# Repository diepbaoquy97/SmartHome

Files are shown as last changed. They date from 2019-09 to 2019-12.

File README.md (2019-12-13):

# Capstone Project
# Fall 2019

##SmartHome
----------
1. [Introduction](#introduction)
2. [Budget](#budget)
3. [Time Commitment](#time-committment)
4. [Mechanical Assembly](#mechanical-assembly)
5. [PCB/ Sodering](#pcb-soldering)
6. [Unit testing](#unit-testing)
7. [Power up](#power-up)
8. [Production Testing](#production-testing)

## Introduction

This is a tutorial which help you do the measuring temperature that using temperature sensor which names MCP9808. This hardware project is used to help the software project name SmartHome. The smarthome app will have some function such as temperature reading, door status, light control. Then the app will control these hardware. This help user overview and control their house easily.

To read the temperature from MCP9808 sensor, we use Raspberry pi 4 with a SD card contain Raspian and we use Linux to write a C program to read the temperature. First, we design the PCB board and do the solder to the socket into PCB. Then we just need to plug in the Raspberry and MCP9808 sensor to the PCB board.

I use the fritzing software to design the PCB board and send it to Humber prototype lab to make the PCB board. The fritzing file could be found [here](https://github.com/diepbaoquy97/SmartHome/blob/master/BaoQuyDiep-Latest.fzz)

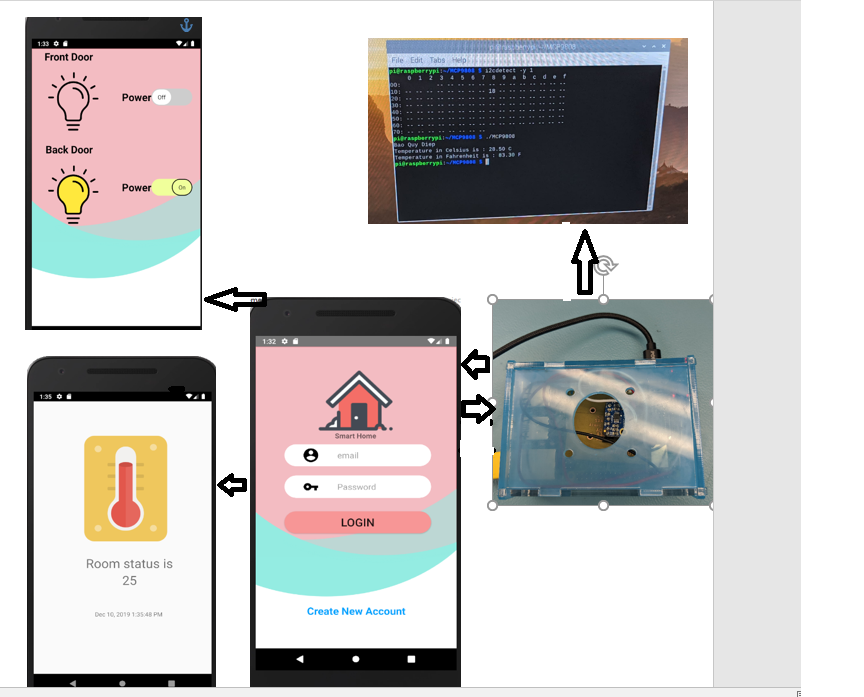
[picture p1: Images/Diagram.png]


## Budget
For me, my budget is approximate $100. The sensor was cheap. The most money I spend is Raspberry. Below is my budget
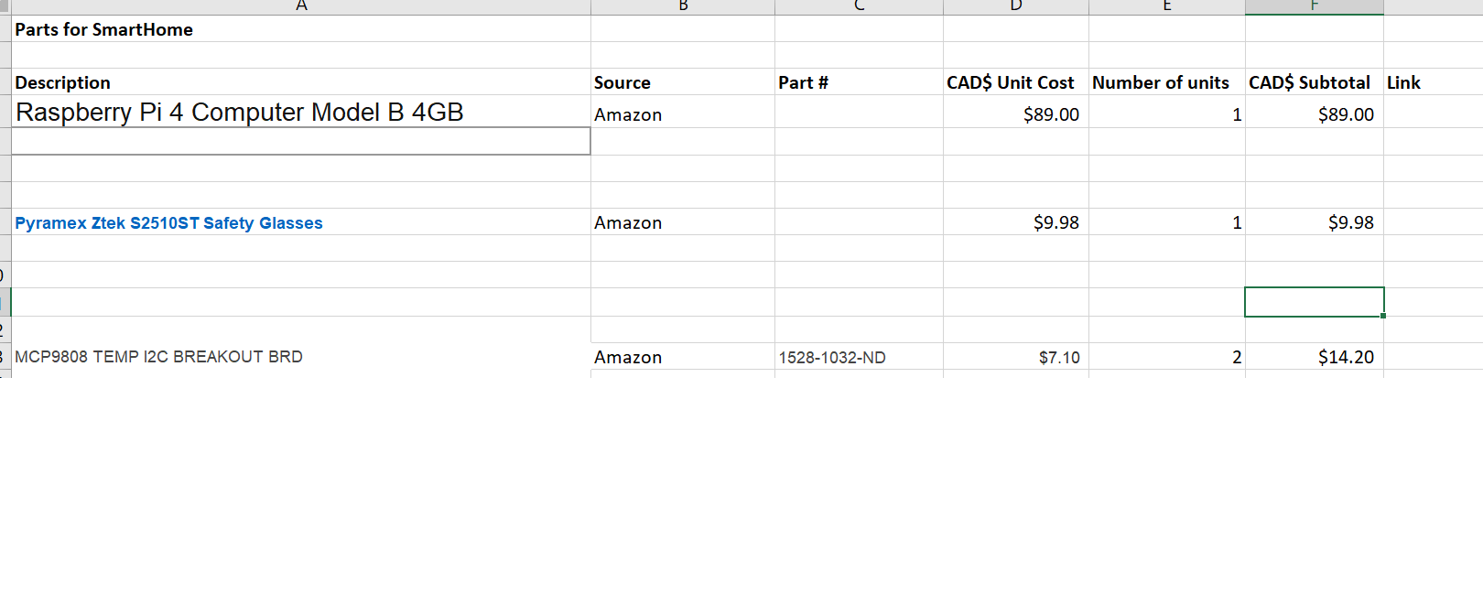
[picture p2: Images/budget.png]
budget


The parts that I got later is 

| Part | Number |
| --- | --- |
| Micro HDMI | 1 |
| USB to Ethernet cable | 1 |
| Raspberry fan | 1 |

I also got 2 x 8 pin socket from the prototype lab

## Time committment 
For this hardware project, it is easy to do and take about 9 hours to comple the project. We just need basic knowledge about circuit connection, soldering skill, Raspberry power up,etc. The longest time is that we have to wait for the parts we order and we also have to wait 2-3 business day for the prototype lab make our PCB board.

| Task | Time |
| --- | --- |
| Ordering | 90 minutes |
| PCB design | 120 minutes |
| Soldering | 60 minutes |
| PCB power up | 120 minutes |
| Enclosure disign | 90 minutes |
| Enclosure pritting | 45 minutes |

In total, It takes approximately 9 hours to complete this project

## Mechanical Assembly
First, we need to connect the circuit from Raspberry to MCP9808 in order to read the temperature. There are 4 pin connection.
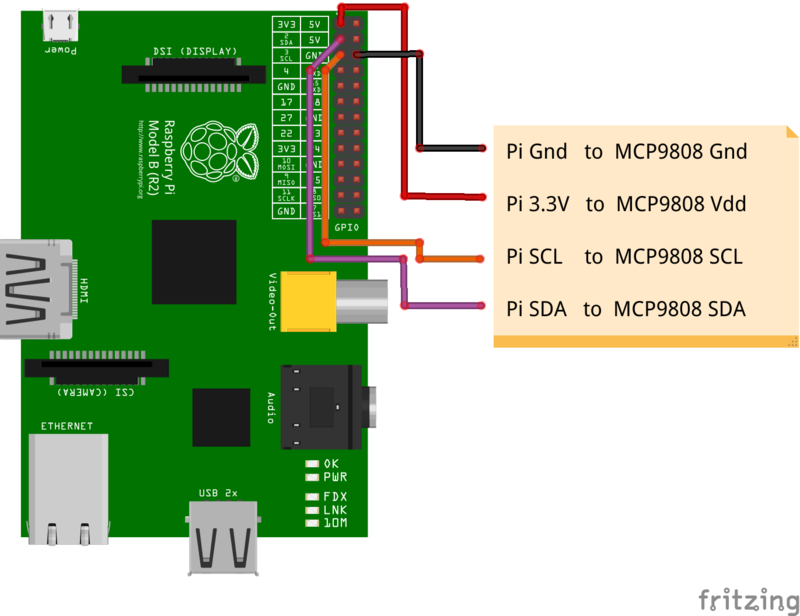
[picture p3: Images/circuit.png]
Circuit


The enclosure for raspberry is designed by the software names Coreldraw. The coreldraw design can be found 
[here](https://github.com/diepbaoquy97/SmartHome/blob/master/BaoCorel17comple.cdr)

The closure could be either printed in prototype lab or private outsite 3D printer.
The example images about enclosure could be found below:
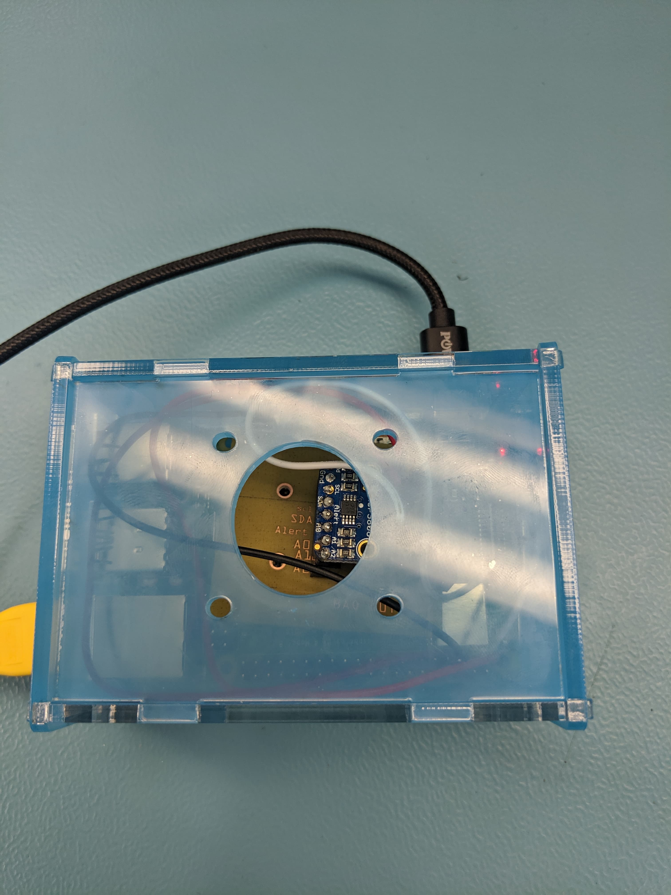
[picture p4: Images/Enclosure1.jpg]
Enclosure1

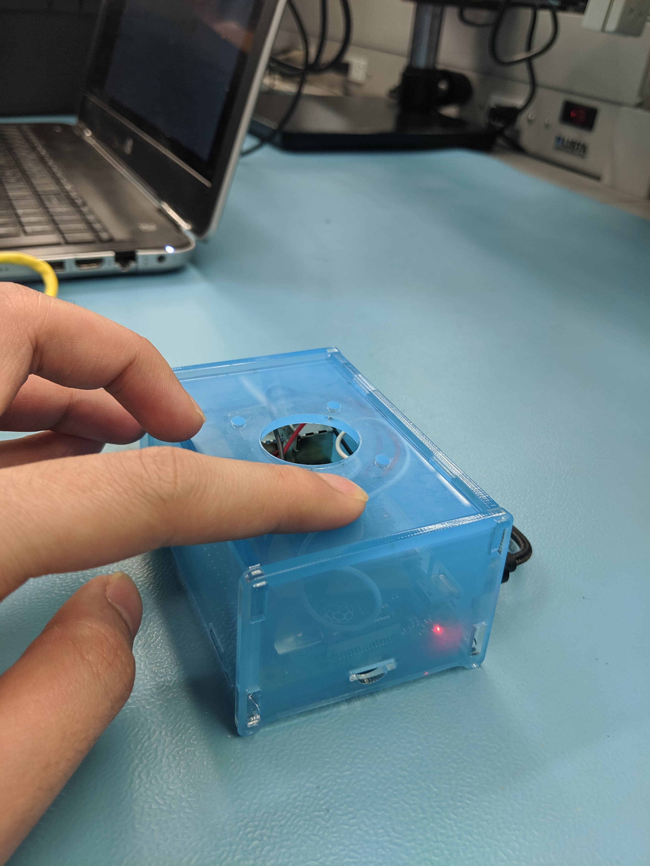
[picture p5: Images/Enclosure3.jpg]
Enclosure3

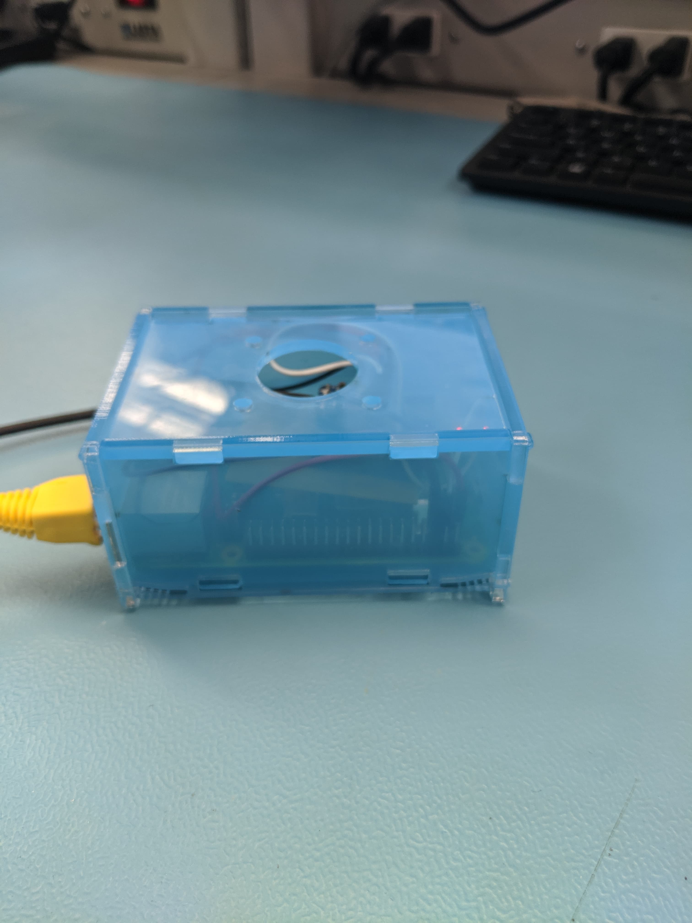
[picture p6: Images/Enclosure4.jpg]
Enclosure4

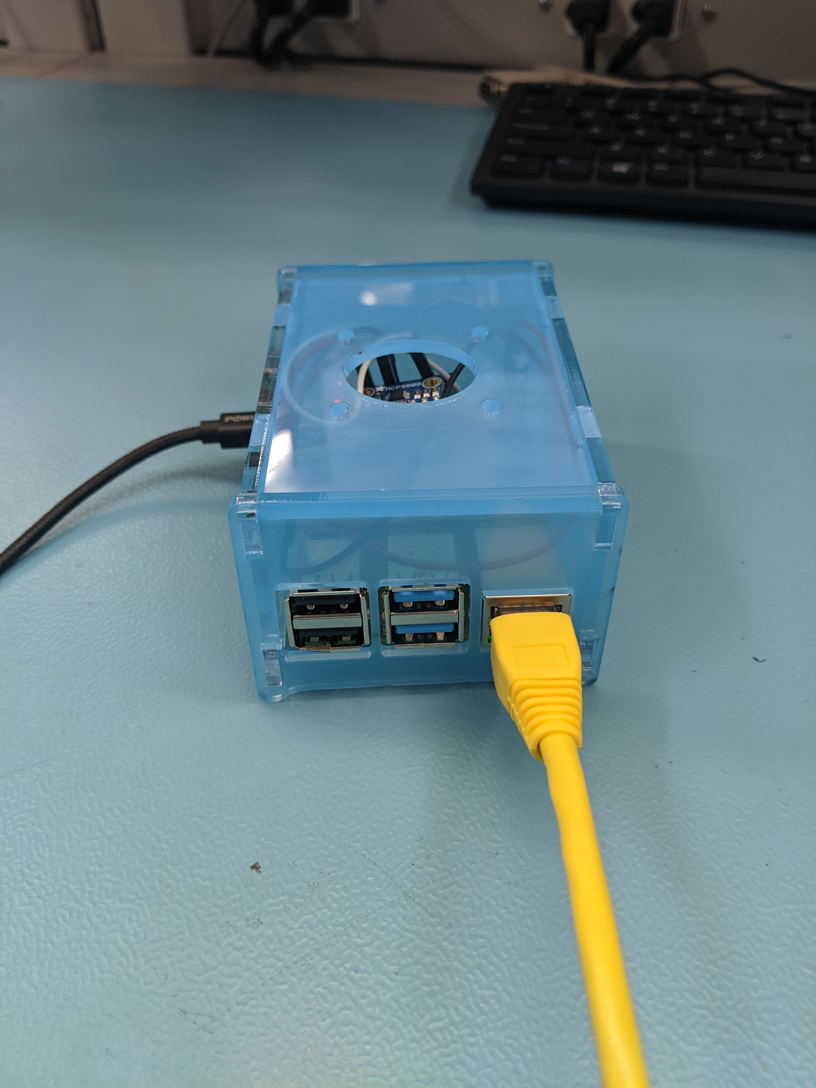
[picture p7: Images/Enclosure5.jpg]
Enclosure5

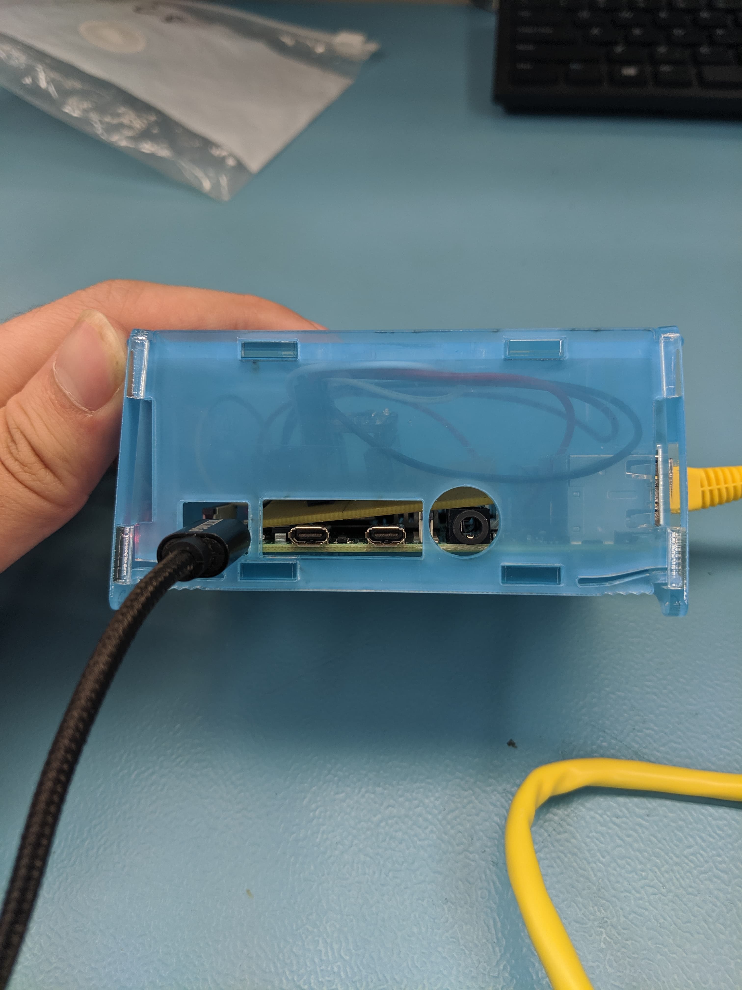
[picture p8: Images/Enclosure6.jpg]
Enclosure6

For the case, just be careful when you put it into the case because it is easy to break

## PCB Soldering
The PBC board must be soldered in order to get connection. We use the socket and put it into the holes and solder it together. Then we just need to plug in the sensor into the socket
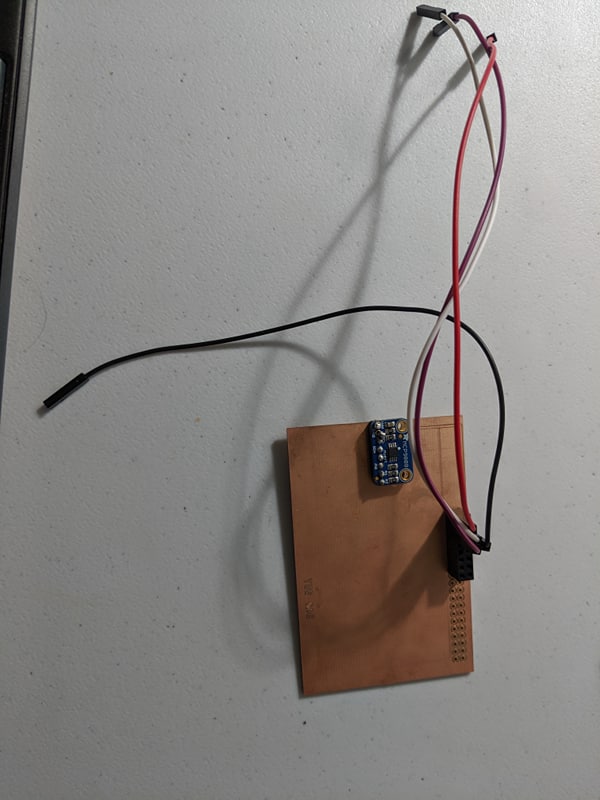
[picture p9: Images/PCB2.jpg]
PCB2


You could found a lot of tutorial about soldering online. Below is the video I found only, it is useful to help solder
[here](https://www.youtube.com/watch?v=aP_ebVWYzSk)

Below is the circuit that we need to solder

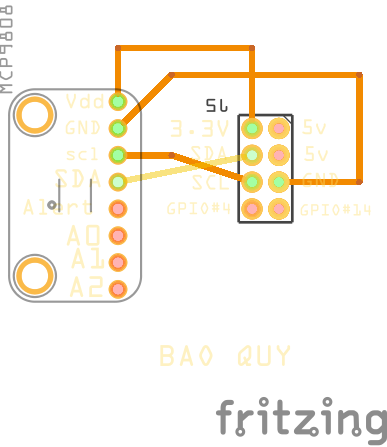
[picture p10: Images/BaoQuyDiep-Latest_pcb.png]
Solder


Warning: Do not solder the sensor directly to the board, we are suppose to solder the socket into the PCB. Be careful when you solder, do not solder too thick it will connect two holes together or too thin and that won't get the connection.

## Unit Testing

### Sensor testing
We have to test the sensor first to see if the sensor function propely. We plug the sensor into the breadboard and use the wire to get connection between Raspberry and sensor. Using the command (sudo i2cdetect -y -1) to see if the connection establish. If it doesn't show up, it means there is no any connection between Raspberry and sensor. So in this case, we should re-check the circuit.
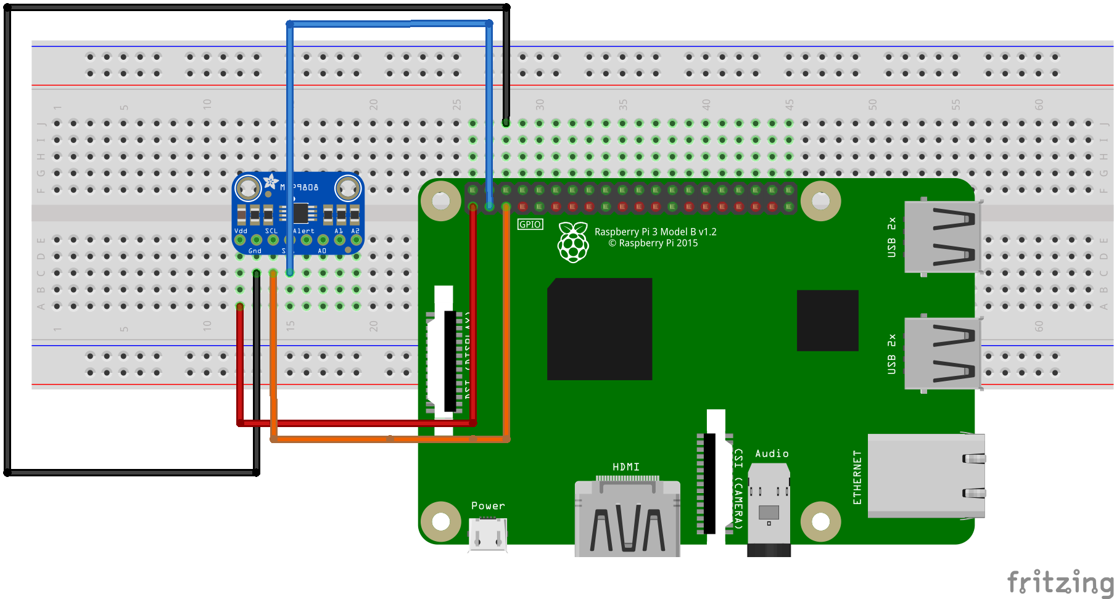
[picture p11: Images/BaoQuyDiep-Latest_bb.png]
Breadboard


If the sensor works properly, then we move on PCB testing.

### PCB testing
Once the PCB get soldered, we have to test all the connection to see if it is propely. First, we use the multimeter to test the connection between Vdd and Ground. If there is overload resistance between them, so there is no connection and this is what we expect. Then move on check the connection between other pin.
If there are incidents that two holes connect together, we could possibly to de-soldering but it will be hard

## Power up

To power up the Raspberry, we need an SD card to load the OS inside it. The link to raspbian is 
[here](https://www.raspberrypi.org/downloads/raspbian/). We recommend to load the virsion name Raspbian Buster with desktop and recommended software because it has full functionality. 

After you download the OS, leave it as zip file. Then download the software call Etcher, you can find it 
[here](https://www.balena.io/etcher/). This software is to flash the Image OS into the SD card. After you load the OS into SD card, insert it into the raspberry. Plug in the power supple

The one time set up is easy, so just follow the step on the OS.

After set everything up, the C file that use to read the temperature could be found 
[here](https://github.com/diepbaoquy97/SmartHome/blob/master/MCP9808.c)
Use the command: gcc -g -o MCP9808 MCP9808.c to complie. Then the execution file will be MCP9808.
#### Notice: If you use the Raspberry 4, it requires lot ofs voltage to power it on. So you should get power supply which support the high voltage. Or another way is to plug it in the USB 3.0 port, it also produces high voltage.

## Production Testing

This is the final testing to make sure the whole project works propely as we expect. Running the wire through the Raspberry case and connect with power supply, ethernet cable. Now running the code that read the temperature and see if it can read the temperature propely by placing your hand on the sensor and then put your hand off the sensor.

This is the concludes the end of build instruction, I hope that you successfully set up the project.

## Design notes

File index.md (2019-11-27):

  
# The CENG 317 smart home
# My Blog

The project is Smart home control. Its functionality is to overview and control the house, reading and set temperature, detect obstacle using motion sensor. It helps people manage home easily and safely.  

# Table of contents
# Week 12: Presentation
This week is presentation about what the project. Below is my powerpoint file. My progress is up to date and my budget is good, there is nothing new to buy.
[Powerpoint](https://github.com/diepbaoquy97/SmartHome/blob/master/SmartHome%20-%20Temperature.pptx)
# Week 11: Enclosure 
This week is about enclosure for the project. The file that I used to print the enclosure at prototype lab can find below
[EnclosureCDR](https://github.com/diepbaoquy97/SmartHome/blob/master/BaoCorel17comple.cdr).

  My closure is a case that cover the raspberry which has my MCP9808 temperature sensor inside to measure the temperature.
Here are some picture about the case
Enclosure1

Enclosure3
Enclosure4
Enclosure5
Enclosure6
My current progress is up to date and my budget is good for now. I got everything I need so there is nothing new to buy.
# Week 10: PCB power up
This week is about PCB power up. At the first time, I soldered the temperature sensor into the PCB board. So I have to send the Gerber file to prototype lab to make a new PCB board. I got the new PCB board on Thursday and did the soldering. It works fine and can read the temperature.
Also for my buget I have got the heat sink and fan and I am going to install to my raspberry, my current buget is good and I am waiting for the socket. My current progress just catch up the plan as I scheduled.
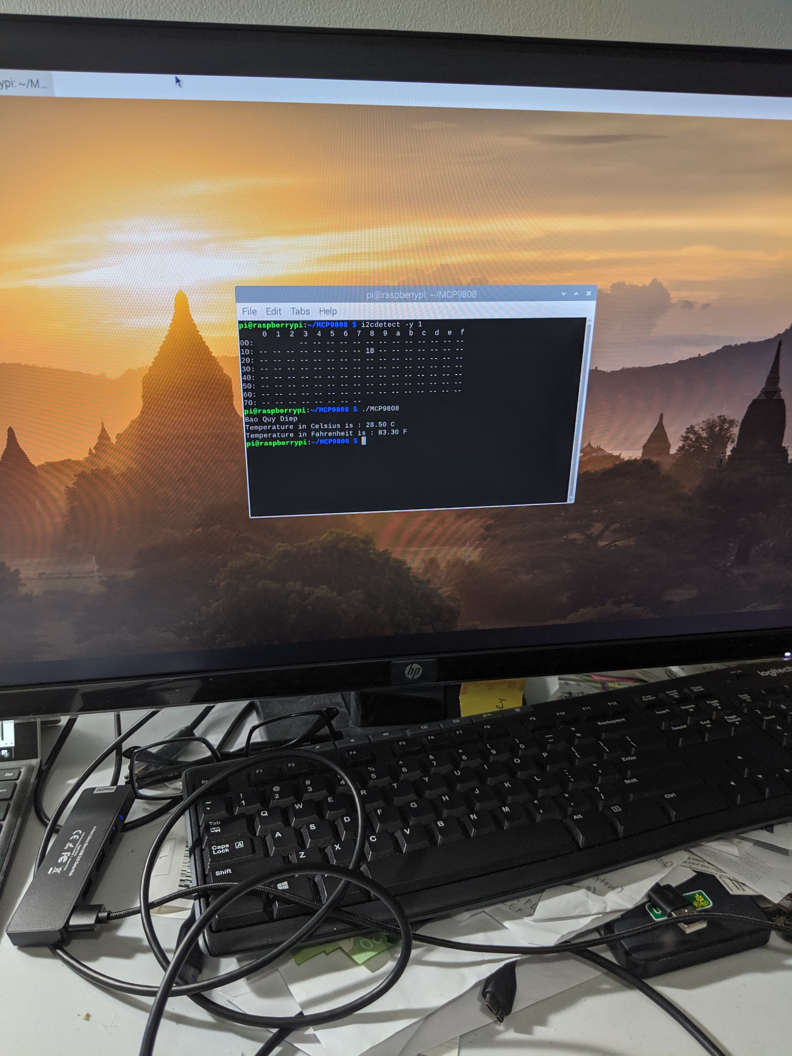
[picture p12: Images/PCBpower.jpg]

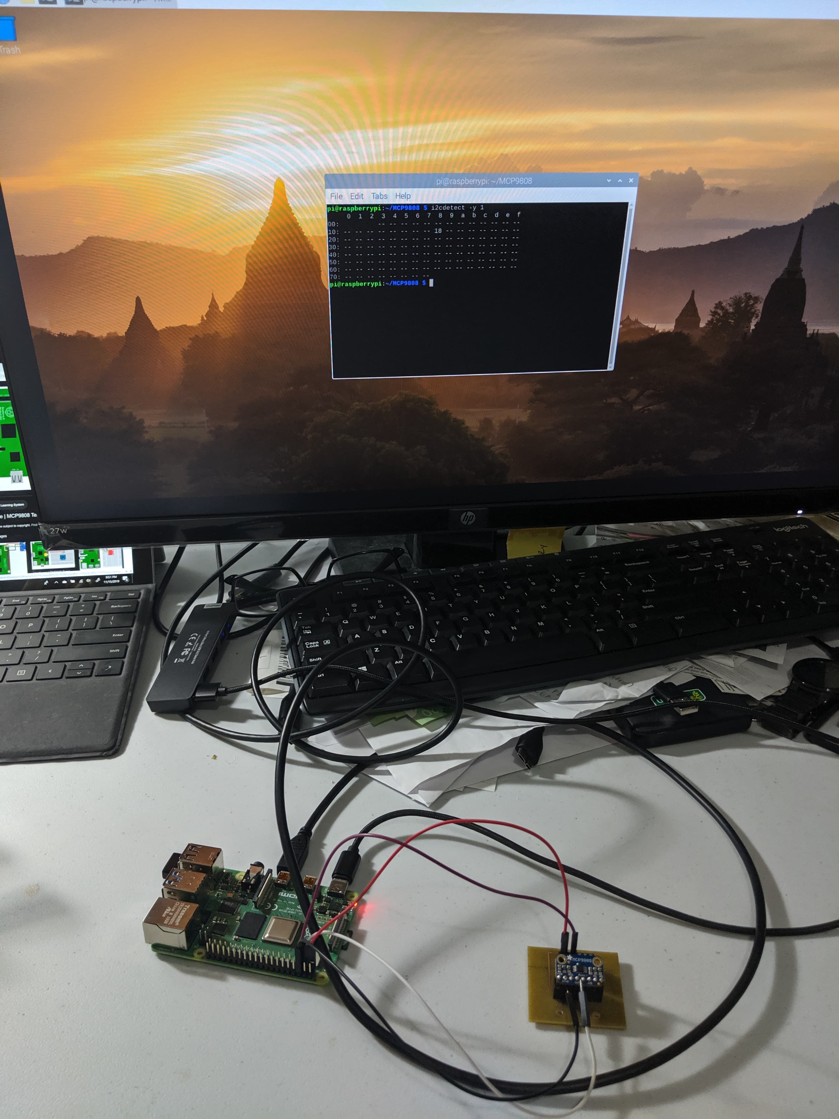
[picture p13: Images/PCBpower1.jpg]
PCB1

# week 9 : PCB soldered
This week is about PCB soldering part. I got a socket and the MCP9808 temperature soldered to the PCB board.At first, by accident I soldered two pins and it connected together. Then I have to reheat it and I was success to get it seperate. Before the end of class,I checked the resistance between the VDD and Ground, there is no connection and that is a good sign. I have finished the PCB soldered milestone for this week so my current progress is on track.

Also, in my budget I need to buy the Ethernet to USB cable in order to connect the raspberry to my laptop using remote control desktop. Moreover, I have ordered a sink heat for my raspberry so It will help the raspberry work smoothly. 

I have mesesured the resistance between Vdd and Ground 
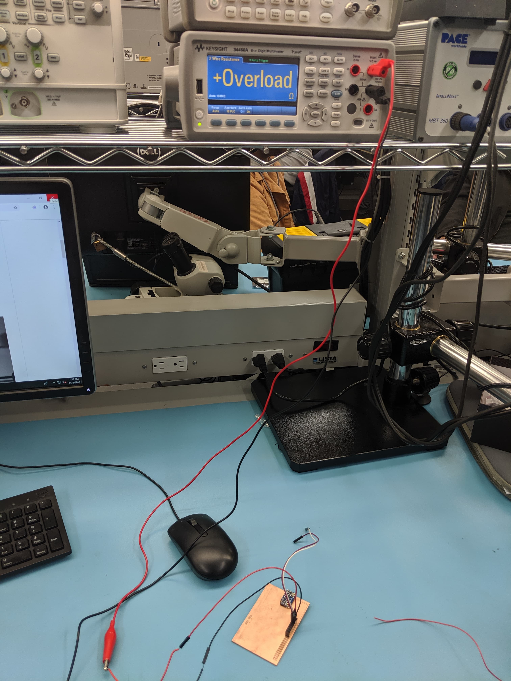
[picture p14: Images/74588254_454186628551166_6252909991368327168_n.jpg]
photp

Here is my PCB board
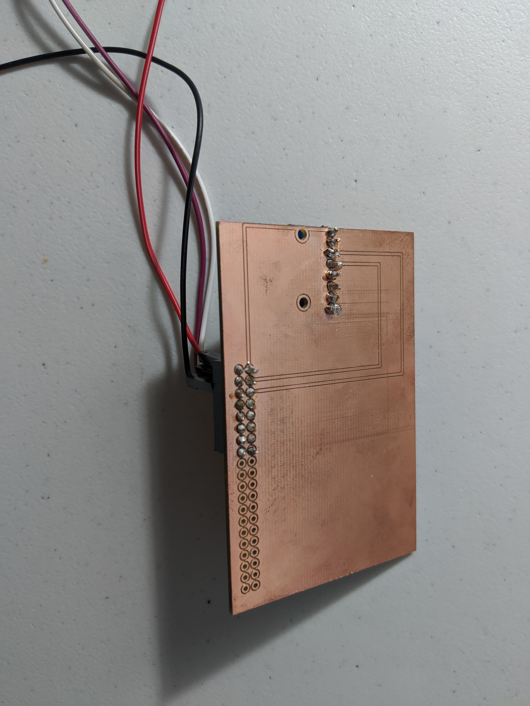
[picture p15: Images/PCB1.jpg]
pcb1

pcb2

# week 8: Breadboarded
My raspberry pi 4 had a problem with booting, it kept rebooting over and over again. The professor had detected the problem that there wasn't enough power to supply the raspberry. He solved the problem by plug it into USB 3.0 port ( the blue port USB) and it can boot up.

This is my circuit which connect MCP9808 temperature sensor to Raspberry. I have solder the parts of MCP9808 into the MCP9808 holes
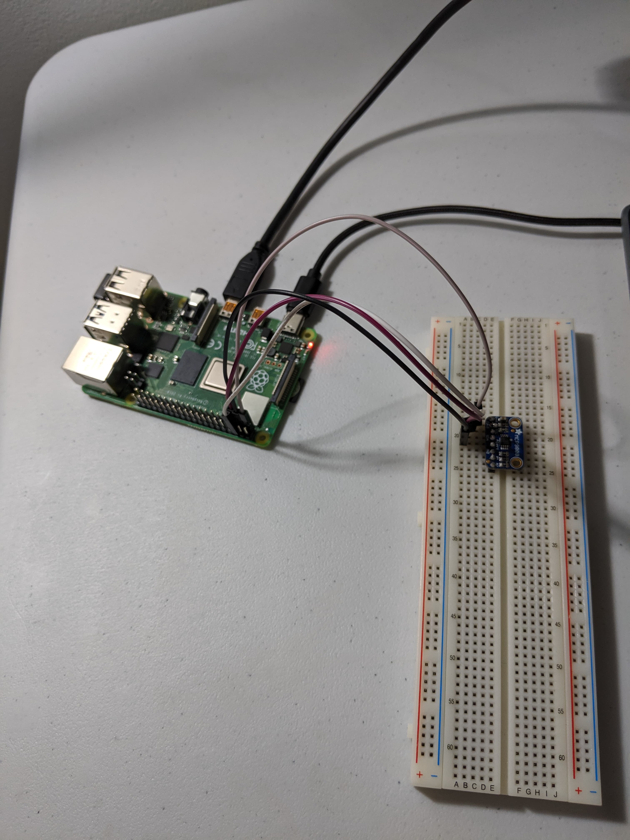
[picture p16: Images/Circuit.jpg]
Circuit


Below is the temperature that the MCP9808 read
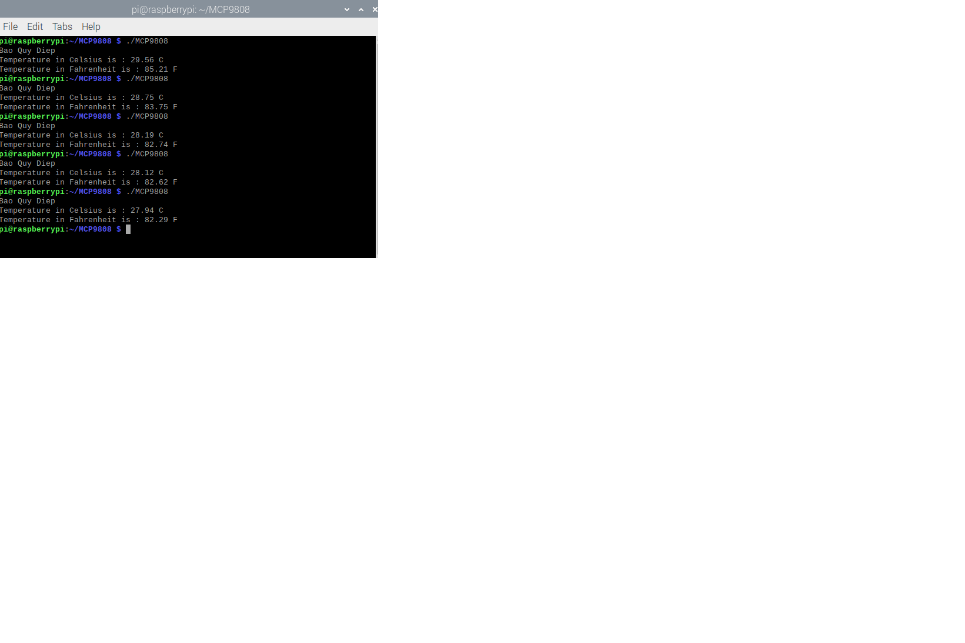
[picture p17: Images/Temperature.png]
Temperature


# Raspberry OS
I have loaded the raspberry OS into the SD card and mounted to raspberry pi. But it can't boot. I am trying to identify the issues
# Week 6: Circuit diagram

This is the fritzing file of my design [Fritzing](https://github.com/diepbaoquy97/SmartHome/blob/master/BaoQuyDiep-Latest.fzz)

This is breadboard diagram

Breadboard

This is PCB diagram that I cut off

PCB

This is the schematic

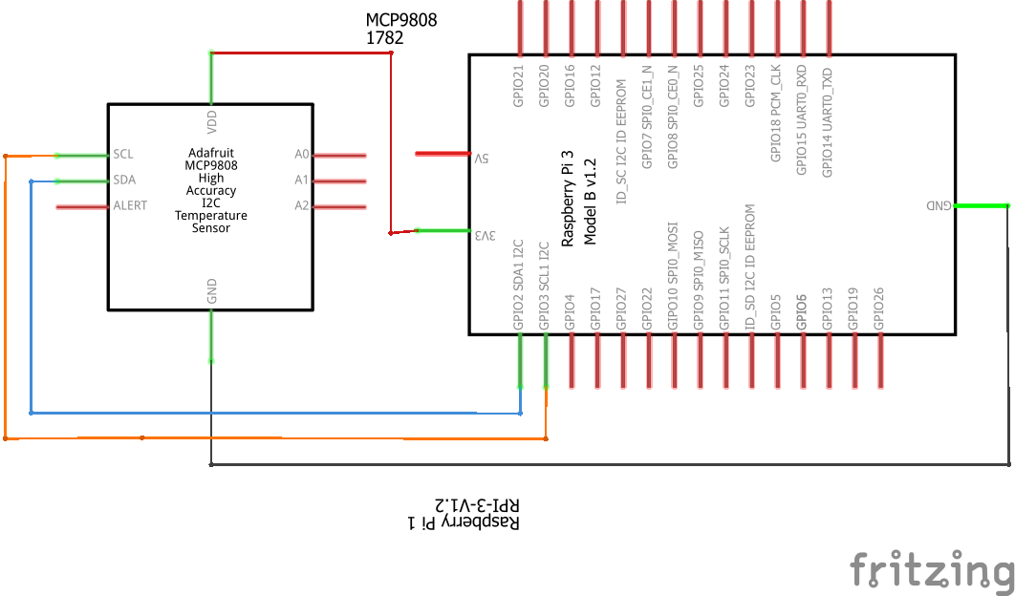
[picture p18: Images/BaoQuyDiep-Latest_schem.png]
Schem


# Order parts has arrived
 I have got all the parts from amazon and digikey and checked it by professor
# Week 5 Proof of purchase
The order I have made

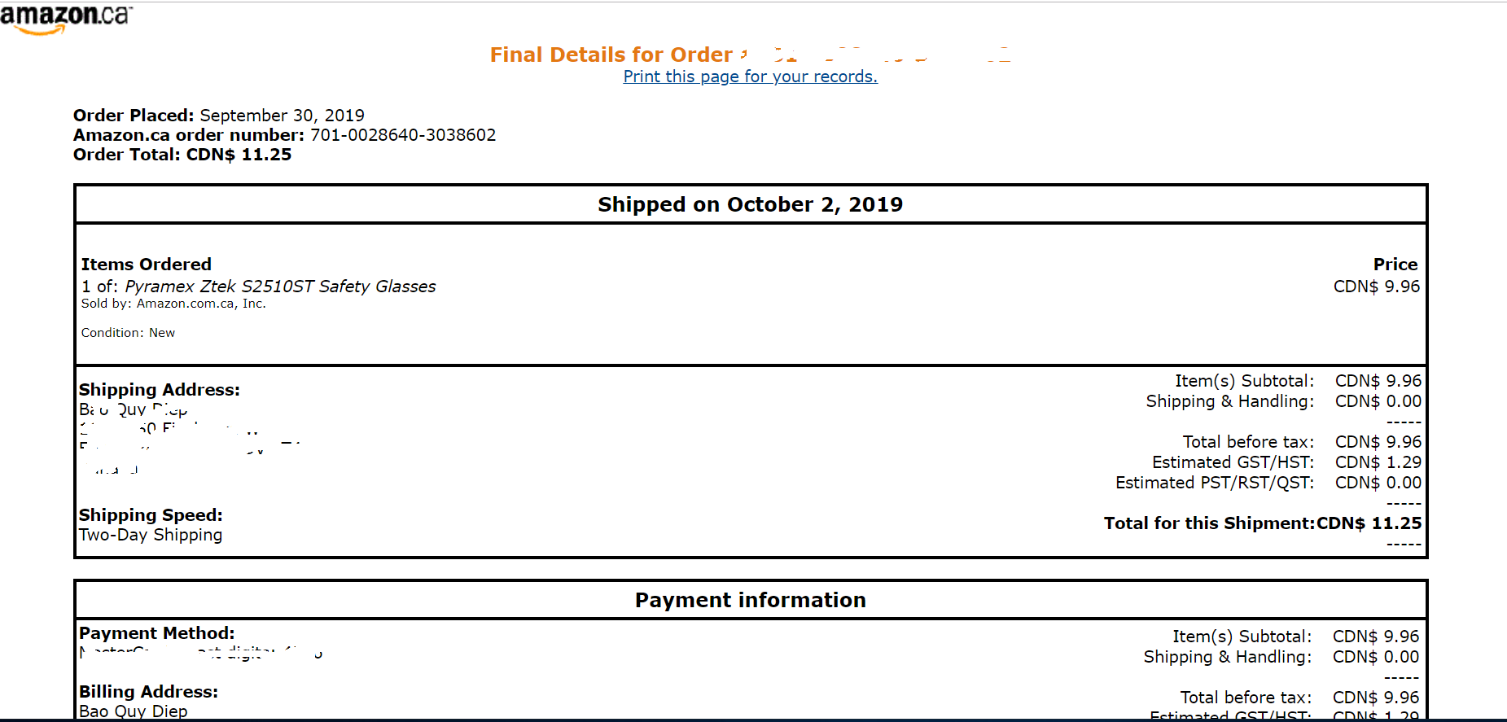
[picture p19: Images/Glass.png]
Glass


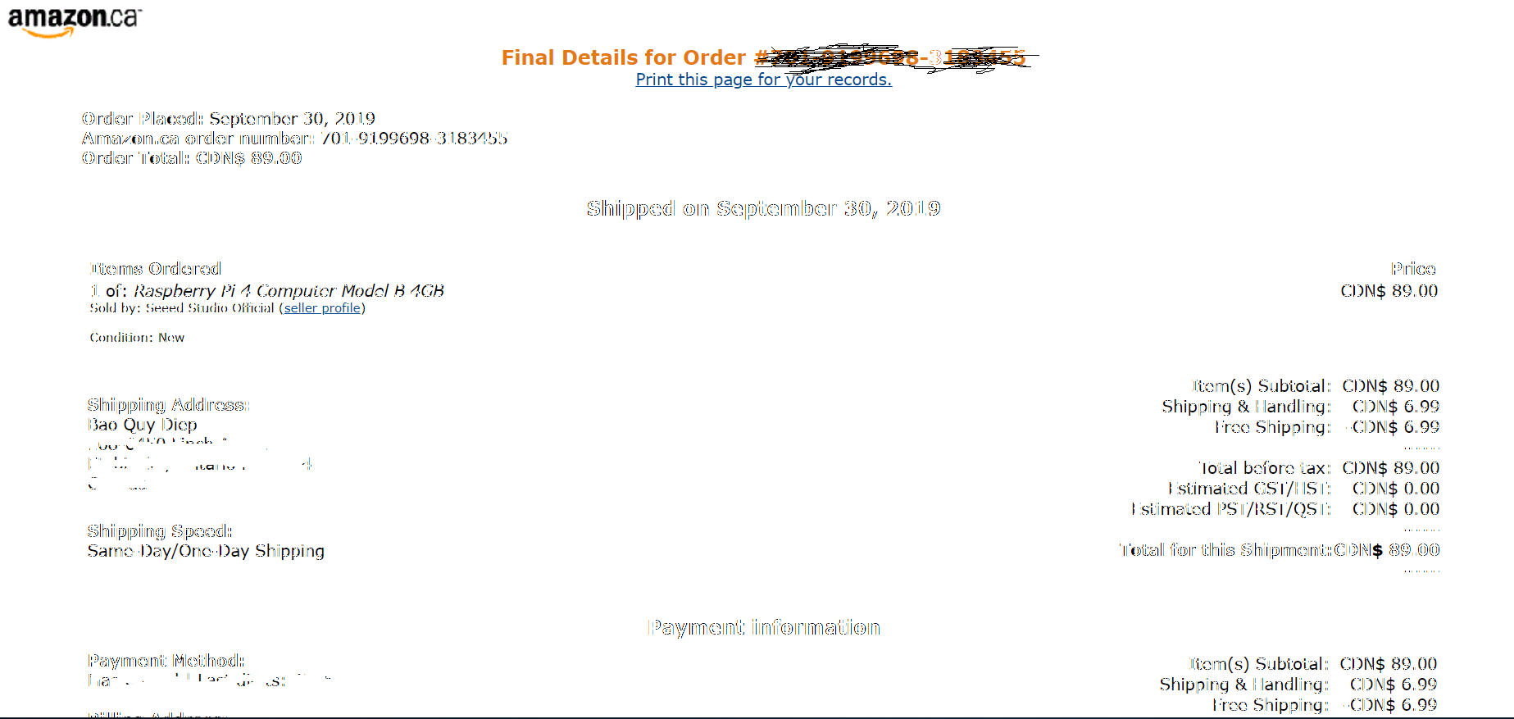
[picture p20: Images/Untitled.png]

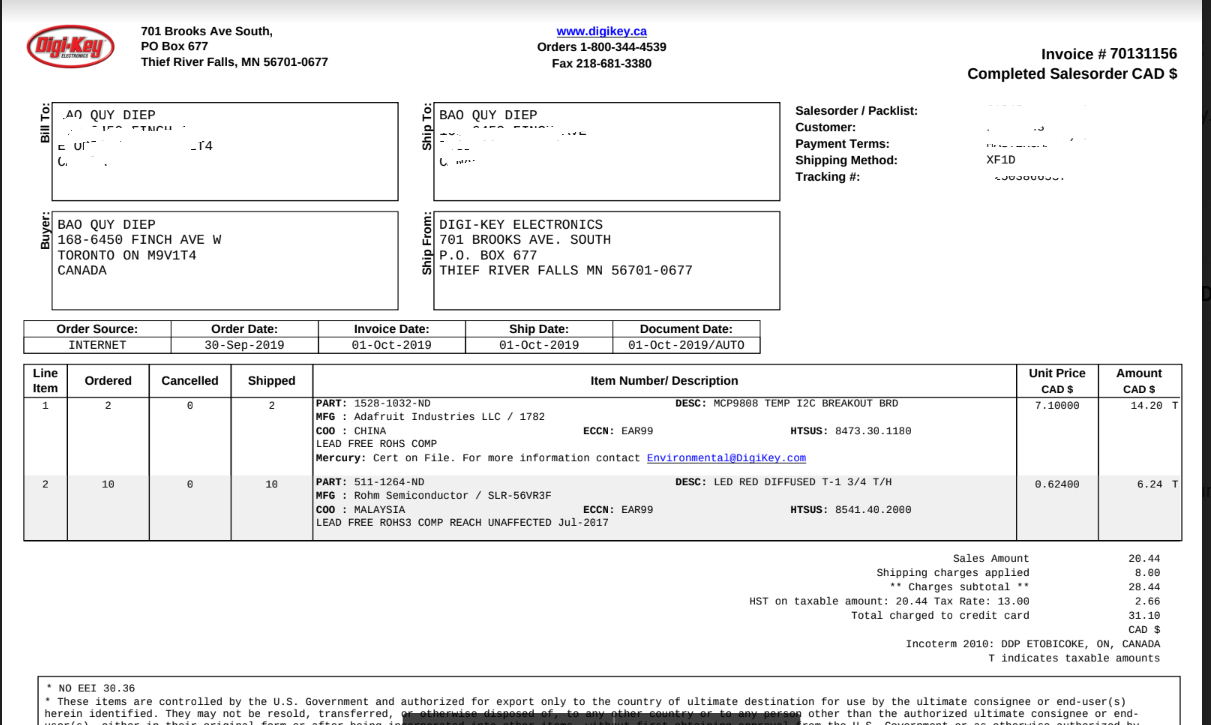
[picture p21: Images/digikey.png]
digikey


# Week 4: Budget
Created [Budget](https://github.com/diepbaoquy97/SmartHome/blob/master/PartsFor2SmartHome_(2).pdf)

# Week 3: Gantt Chart
Created [GanttChart](https://github.com/diepbaoquy97/SmartHome/blob/master/Gantt.xlsx)
# Week 2: Proposal created
Created [Proposal](https://github.com/diepbaoquy97/SmartHome/blob/master/Proposal.xlsx)

# Sep 10 : Reposistory Created

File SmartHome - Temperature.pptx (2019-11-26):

## Smart Home Project

Temperature sensor

## Proposal

- The project we want to build is a smart home system; it will connect sensors and interactive functional devices of a home with an app and a database. The purpose of this project is to give the user control and overview of their home
- Temperature sensor MCP9808
- MCP9808 is I2C digital temperature sensor
- Accuracy of ±0.25°C over the sensor's -40°C to +125°C range

## MCP9808

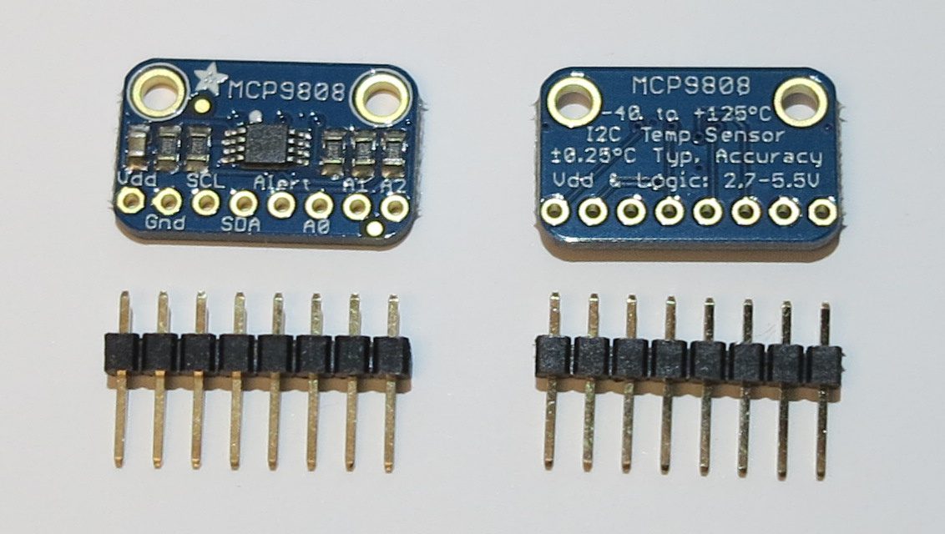
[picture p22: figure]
Image result for MCP9808 to raspberry

## Circuit diagram

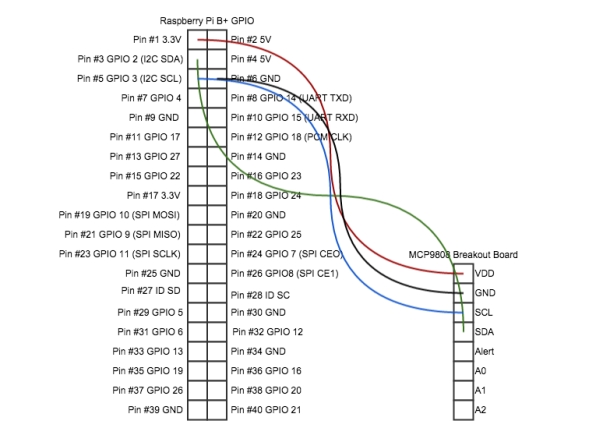
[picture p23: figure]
Image result for MCP9808 to raspberry

## Schedule

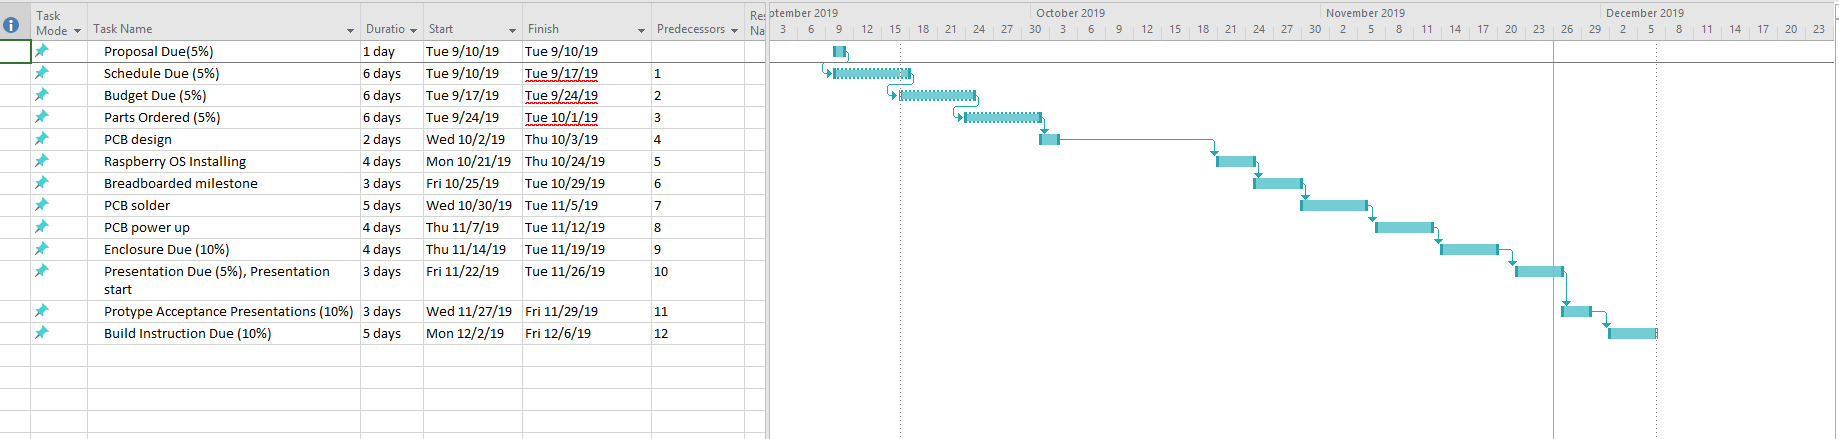
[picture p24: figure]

## Budget

- Raspberry 4 from Amazon is $89
- MCP9808 temperature sensor is $7.10

## Image about project

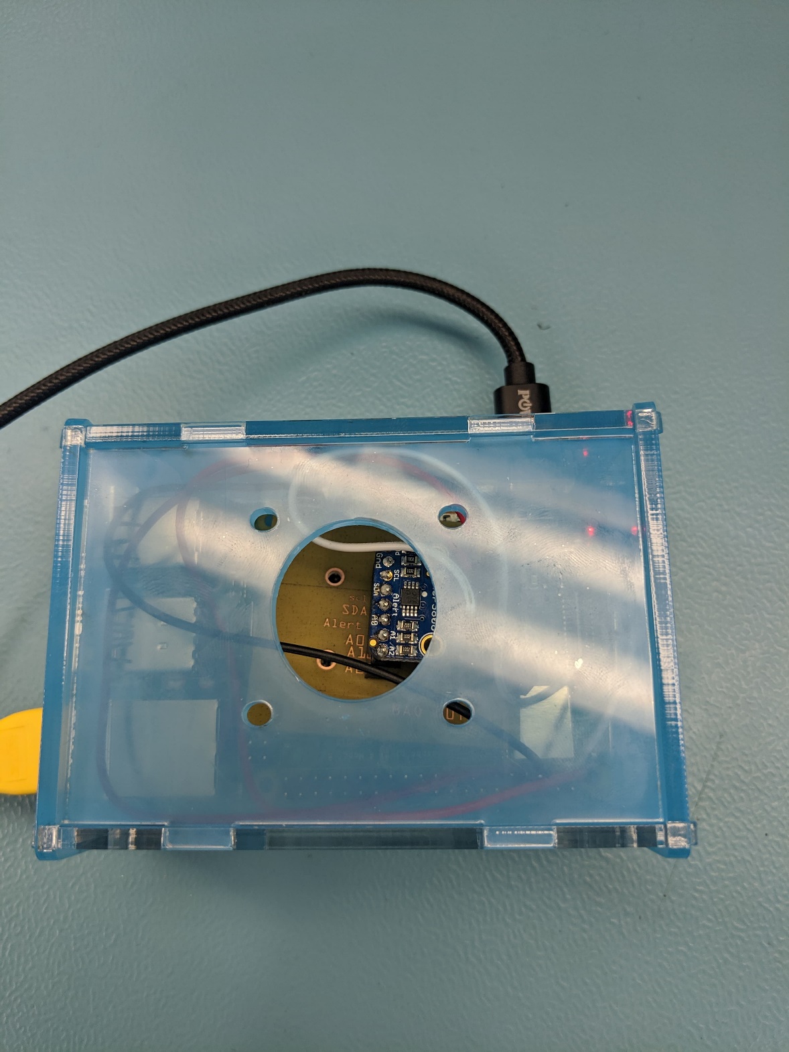
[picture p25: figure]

## Enclosure

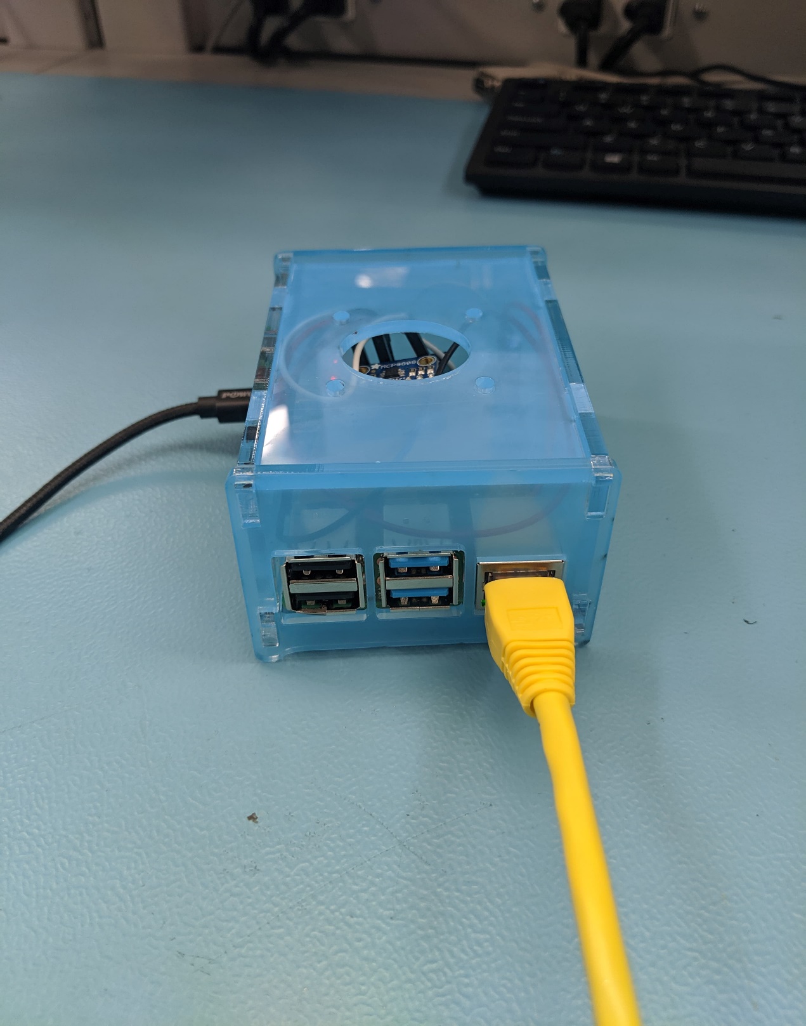
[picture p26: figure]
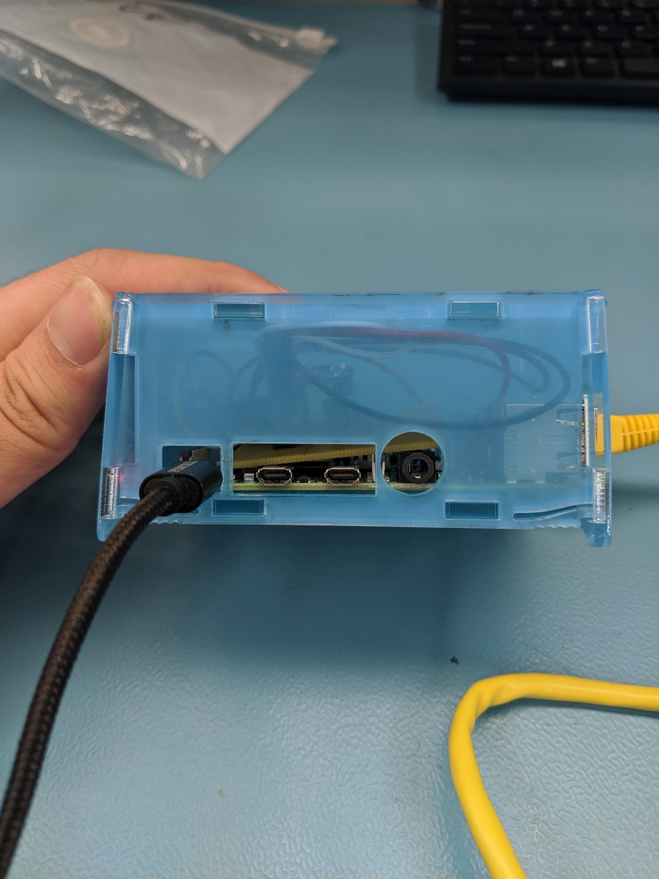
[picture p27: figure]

## Sensor address

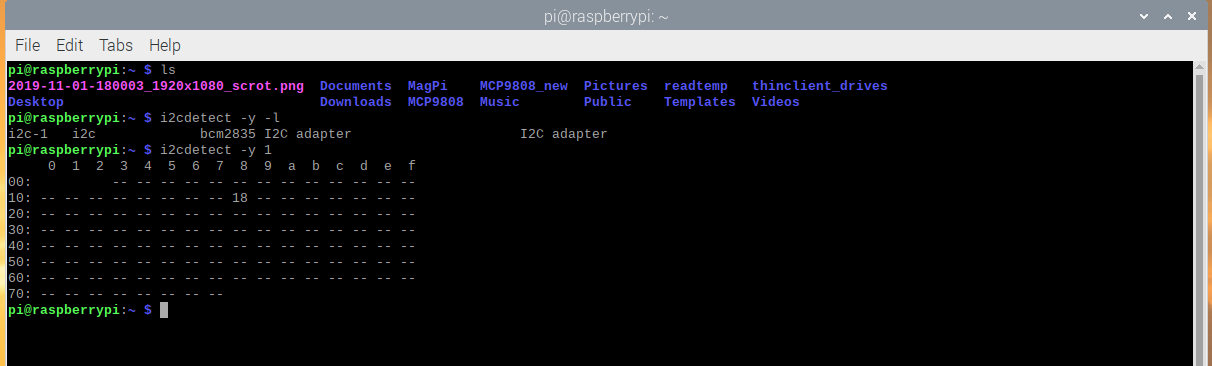
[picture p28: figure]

## Knowndge from previous course

- Tech 150 – Device and circuit – Soldering skill
- Tech 103 – Digital and fundamental – Circuit connection

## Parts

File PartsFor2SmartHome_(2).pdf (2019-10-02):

Parts for SmartHome

Description | Source | Part # | CAD$ Unit Cost | Number of units | CAD$ Subtotal | Link
Raspberry Pi 4 Computer Model B 4GB | Amazon | | $89.00 | 1 | $89.00
Pyramex Ztek S2510ST Safety Glasses | Amazon | $9.98 | 1 | $9.98
Red 630nm LED Indication - Discrete 2V Radia | Digitkey | 511-1264-ND | $0.62 | 10 | $6.24
MCP9808 TEMP I2C BREAKOUT BRD | Amazon | 1528-1032-ND | $7.10 | 2 | $14.20
Adafruit Tax | 0
Total for parts from CAD sources | $119.42

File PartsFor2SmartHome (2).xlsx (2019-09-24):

Parts for SmartHome
Description | Source | Part # | CAD$ Unit Cost | Number of units | CAD$ Subtotal | Link
Arduino Uno R3 ATmega328P Microcontroller Card & USB Cable for Electronics & Robotics | Amazon |  | $15.82 | 1 | $15.82
SENSOR ANALOG 10C-125C TO92-3 | Digitkey | TMP35GT9Z (https://www.digikey.ca/product-detail/en/analog-devices-inc/TMP35GT9Z/TMP35GT9Z-ND/996945) | $7.12 | 3 | $21.36
Pyramex Ztek S2510ST Safety Glasses | Amazon |  | $9.98 | 1 | $9.98
ST-LINK/V2‎ | Digitkey | 497-10484-ND | $32.42 | 1 | $32.42
Red 630nm LED Indication - Discrete 2V Radia | Digitkey | 511-1264-ND | $0.62 | 10 | $6.24
LCD Display Digital Refrigerator Fridge Freezer Thermometer Temperature 50 Below To 110C (Black) | Amazon |  | $3.08 | 1 | $3.08
IC MCU 32BIT 64KB FLASH 48LQFP | Digitkey | 497-6063-ND | $9.25 | 2 | $18.50
 |  |  |  |  | $0.00
PCB | Digitkey | HM1250-ND | $11.21 | 2 | $22.42
Adafruit Tax | 0
Total for parts from CAD sources |  |  |  |  | $129.82

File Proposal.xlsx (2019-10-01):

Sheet: DataEntry
Submission Date | 2019-09-10
Project Name | IoT for SmartHome
Student Names | Bao Quy Diep, Vyacheslav Perepelytsya
Project repository | https://github.com/diepbaoquy97/SmatHome
SensorsEffectors choices | Temperature sensor, light sensor
The database will store | Firebase
The mobile device functionality will include | Bluetooth access, wifi access
I will be collaborating with the following company/department
My group in the winter semester will include | Bao Quy Diep
50 word problem statement | We have an issue that connects things together in the house
100 words of background | We basicaly do the control and oview for the house that helps us easily have a good oview about the house such as status of lighting, temperature, security camera, etc.
Current product APA citation | Top 5 Components Of a Smart Home Janet Veach - https://www.amerifirst.com/amerifirst-blog/bid/106899/top-5-components-of-a-smart-home
Existing research IEEE paper APA citation | https://www.makeuseof.com/tag/budget-smart-home-projects/
Brief description of planned purchases | I am going to get temperature sensor , light sensor and smart plug which
Solution description | We try to read the temperature of the house first, then get the light sensor install to save electrocity and then using the smart plug which able to connect to wifi to control the light

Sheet: DataBase
Submission Date | Project Name | Student Names | Project repository | SensorsEffectors choices | The database will store | The mobile device functionality will include | I will be collaborating with the following company/department | My group in the winter semester will include | 50 word problem statement | 100 words of background | Current product APA citation | Existing research IEEE paper APA citation | Brief description of planned purchases | Solution description
43718 | IoT for SmartHome | Bao Quy Diep, Vyacheslav Perepelytsya | https://github.com/diepbaoquy97/SmatHome | Temperature sensor, light sensor | Firebase | Bluetooth access, wifi access | 0 | Bao Quy Diep | We have an issue that connects things together in the house | We basicaly do the control and oview for the house that helps us easily have a good oview about the house such as status of lighting, temperature, security camera, etc. | Top 5 Components Of a Smart Home Janet Veach - https://www.amerifirst.com/amerifirst-blog/bid/106899/top-5-components-of-a-smart-home | https://www.makeuseof.com/tag/budget-smart-home-projects/ | I am going to get temperature sensor , light sensor and smart plug which | We try to read the temperature of the house first, then get the light sensor install to save electrocity and then using the smart plug which able to connect to wifi to control the light

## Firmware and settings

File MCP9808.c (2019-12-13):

// Distributed with a free-will license.
// Use it any way you want, profit or free, provided it fits in the licenses of its associated works.
// MCP9808
// This code is designed to work with the MCP9808_I2CS I2C Mini Module available from ControlEverything.com.
// https://www.controleverything.com/content/Temperature?sku=MCP9808_I2CS#tabs-0-product_tabset-2

#include <stdio.h>
#include <stdlib.h>
#include <linux/i2c-dev.h>
#include <sys/ioctl.h>
#include <fcntl.h>

void main() 
{
	// Create I2C bus
	int file;
	char *bus = "/dev/i2c-1";
	if ((file = open(bus, O_RDWR)) < 0) 
	{
		printf("Failed to open the bus. \n");
		exit(1);
	}
	// Get I2C device, MCP9808 I2C address is 0x18(24)
	ioctl(file, I2C_SLAVE, 0x18);

	// Select configuration register(0x01)
	// Continuous conversion mode, Power-up default(0x00, 0x00)
	char config[3] = {0};
	config[0] = 0x01;
	config[1] = 0x00;
	config[2] = 0x00;
	write(file, config, 3);
	// Select resolution rgister(0x08)
	// Resolution = +0.0625 / C(0x03)
	config[0] = 0x08;
	config[1] = 0x03;
	write(file, config, 2);
	sleep(1);

	// Read 2 bytes of data from register(0x05)
	// temp msb, temp lsb
	char reg[1] = {0x05};
	write(file, reg, 1);
	char data[2] = {0};
	if(read(file, data, 2) != 2)
	{
		printf("Error : Input/Output error \n");
	}
	else
	{
		// Convert the data to 13-bits
		int temp = ((data[0] & 0x1F) * 256 + data[1]);
		if(temp > 4095)
		{
			temp -= 8192;
		}
		float cTemp = temp * 0.0625;
		float fTemp = cTemp * 1.8 + 32;


		printf("Bao Quy Diep\n");
		// Output data to screen
		printf("Temperature in Celsius is : %.2f C \n", cTemp);
		printf("Temperature in Fahrenheit is : %.2f F \n", fTemp);
	}
}

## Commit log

2019-09-24 Add files via upload
    My Budget
    [PartsFor2SmartHome (2).xlsx]
2019-10-01 Add files via upload
    Proposal
    [Proposal.xlsx]
